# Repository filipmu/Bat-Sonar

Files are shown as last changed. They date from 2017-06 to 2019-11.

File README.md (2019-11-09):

# Bat-Sonar
Bat like sonar sensor that can track multiple targets and estimate angle of arrival using chirps and cross correlation in near real time.  Code for a ARM Cortex signal processing project I completed and published on hackaday.io. 

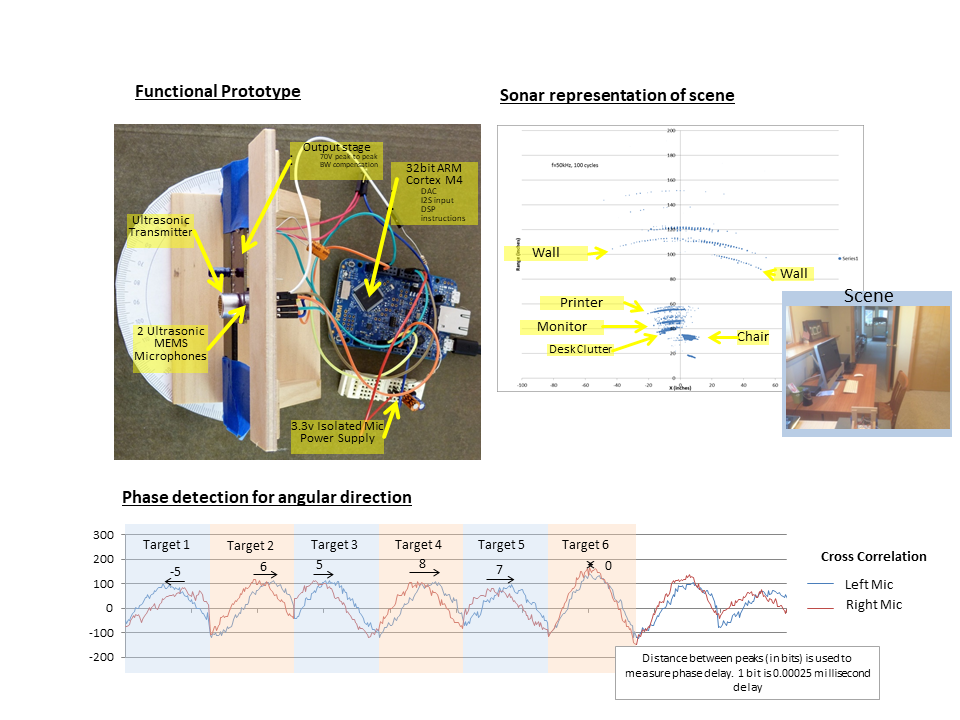
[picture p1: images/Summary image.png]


## Video
This video shows the sensor in action.  The left graph shows the identified targets.  The size of the circles indicates the strength, and the location on the graph is their measured location.  The graph on the right shows the cross correlation signal vs distance.  The first step is pressing a switch on the board to calibrate and baseline the sensor.  Then the video shows the sensor identifying various targets.:https://vimeo.com/250041155

## How it works
The approach works natively on the 1-bit PDM output of MEMS microphones.  Since the sample rate is 4MHz, very accurate phase comparison can be done. This approach takes advantage of how the cross correlation problem simplifies when its matching a simple square wave chirp with a 1-bit PDM stream. In this case its a sum of delays with terms reflecting the signal level changes in the chirp  and delays reflecting the length of each pulse in the chirp.  This reduces the computational complexity significantly.  Note that its done in the time domain, not using the FFT as is typical with higher resolution digital samples.  The Cortex M4 has SIMD (Single Instruction Multiple Data) and DSP instructions that I carefully tuned to maximize computation speed. The theory is in this paper: :http://www.kurosawa.ip.titech.ac.jp/publications/papers/ieice08sh.pdf
 
 A much more detailed description of how it works can be found at :https://hackaday.io/project/29512-bat-sonar/details

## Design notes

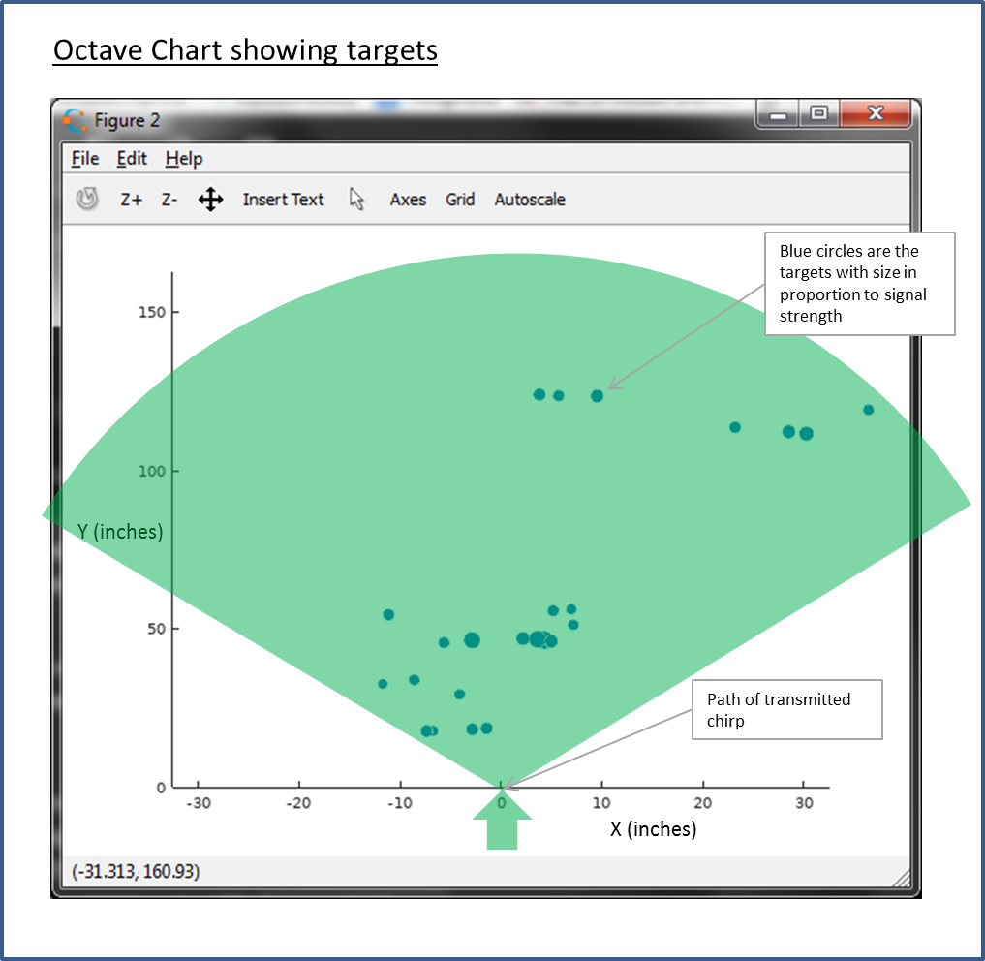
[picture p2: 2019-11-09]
images/octave chart showing targets.png

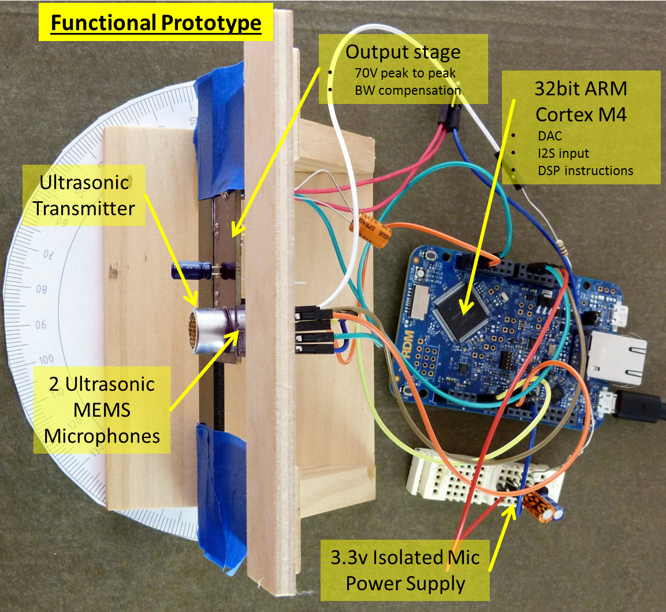
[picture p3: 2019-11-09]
images/labelled picture.png

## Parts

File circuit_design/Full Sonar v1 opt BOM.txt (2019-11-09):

Partlist exported from C:/Users/Filip/eagle/projects/Sonar/Full Sonar v1 opt.sch at 2/24/2018 7:42 AM

Qty Value                      Device                     Package                    Parts                                    Description                                                                   
1                              DIODE_SCHOTTKYMICROSMP     DIODE_SCHOTTKY_MICROSMP    D1                                       Schottky Power Rectifier                                                      
1                              MA05-1                     MA05-1                     SV1                                      PIN HEADER                                                                    
1   +5-9v                      MA02-1                     MA02-1                     J6                                                                                                                     
1   .1uF                       C-USC0603                  C0603                      C14                                      CAPACITOR, American symbol                                                    
9   0.1uF                      C-USC0603                  C0603                      C2, C5, C6, C10, C11, C16, C17, C18, C19 CAPACITOR, American symbol                                                    
2   0.1uF                      C-USC0603K                 C0603K                     C15, C20                                 CAPACITOR, American symbol                                                    
1   10                         R-US_R0603                 R0603                      R13                                      RESISTOR, American symbol                                                     
5   100K                       R-US_R0603                 R0603                      R2, R5, R6, R7, R8                       RESISTOR, American symbol                                                     
2   10K                        R-US_R0603                 R0603                      R3, R4                                   RESISTOR, American symbol                                                     
1   10uF                       C-USC0603                  C0603                      C21                                      CAPACITOR, American symbol                                                    
2   10uF                       C-USC1206                  C1206                      C1, C23                                  CAPACITOR, American symbol                                                    
1   15                         R-US_R0603                 R0603                      R16                                      RESISTOR, American symbol                                                     
2   1K                         R-US_R0603                 R0603                      R12, R18                                 RESISTOR, American symbol                                                     
2   1uF                        C-USC0603                  C0603                      C3, C7                                   CAPACITOR, American symbol                                                    
1   20K                        R-US_R0603                 R0603                      R9                                       RESISTOR, American symbol                                                     
3   22uF                       C-USC0805                  C0805                      C8, C9, C22                              CAPACITOR, American symbol                                                    
1   22uH                       INDUCTOR7                  INDUCTOR_BOURNS_SRN3012TA  L1                                                                                                                     
1   240K                       R-US_R0603                 R0603                      R10                                      RESISTOR, American symbol                                                     
1   4.7uF                      CPOLA                      TE-A-3216                  C13                                      polarized SMD caps                                                            
1   40V                        TESTPAD""                  TESTPAD                    T2                                                                                                                     
2   499                        R-US_R0603                 R0603                      R1, R11                                  RESISTOR, American symbol                                                     
1   5uH                        INDUCTOR                   INDUCTOR_BOURNS_SDR0503    L2                                                                                                                     
1   65                         R-US_R0603                 R0603                      R17                                      RESISTOR, American symbol                                                     
1   A/D                        MA03-1                     MA03-1                     J4                                       PIN HEADER                                                                    
1   CLV1L-FKB-CJMNQEGBB7673673 CLV1L-FKB-CJMNQEGBB7673673 SOJ150P350X372-4N          U1                                       None                                                                          
1   DAC Out                    TESTPAD""                  TESTPAD                    T                                                                                                                      
1   ECS-3225S33-500-FN-TR      ECS-3225S33-500-FN-TR      XTAL_ECS-3225S18-050-EN-TR Y1                                       Miniature SMD HCMOS tight stability crystal oscillator                        
1   EVP-BB2A9B000              EVP-BB2A9B000              SW_EVP-BB2A9B000           S2                                       SWITCH TACTILE SPST-NO 0.02A 15V                                              
1   I2C                        MA03-1                     MA03-1                     J2                                       PIN HEADER                                                                    
1   I2S Clk                    TESTPAD""                  TESTPAD                    T1                                                                                                                     
1   LD1117AS33                 LD1117AS33                 SOT223                     U$5                                                                                                                    
1   MC34072                    MC34072                    WQFN10                     IC2                                      Dual Precision, Low Cost, High Speed Op Amp +44v supply                       
1   MIC2297                    MIC2297                    MLF10                      IC1                                      40V PWM Boost Regulator White LED Driver                                      
1   MK64FN1M0VLL12             MK64FN1M0VLL12             QFP50P1600X1600X170-100N   U2                                       MCU 32-Bit K64F ARM Cortex M4 RISC 1MB Flash 1.8V/2.5V/3.3V 100-Pin LQFP Tray 
4   MOUNT-HOLE                 MOUNT-HOLE                 SCREWHOLE2-56              H1, H2, H3, H5                           MOUNTING HOLE with drill center marker                                        
1   Output                     MA05-1                     MA05-1                     SV2                                      PIN HEADER                                                                    
1   SI7006                     SI7006                     SI7006                     U$1                                      The Si7006 is an I2C Humidity and Temperature Sensor                          
2   SPH0641LU4H-1              SPH0641LU4H-1              SPH0641LU4H-1              LEFT_MIC, RIGHT_MIC                      Knowles MEMS microphone - ultrasonic range                                    
1   SWD                        62201021121                62201021121                J5                                       WR-PHD 1.27mm Dual Pin Header, 10 Pins=>Code : Con_BTB_PHD_1.27_2_62201021121 
1   UART                       MA03-1                     MA03-1                     J3                                       PIN HEADER                                                                    
1   UT-1240K-TT-R              UT-1240K-TT-R              UT-1240K-TT-R              U$2

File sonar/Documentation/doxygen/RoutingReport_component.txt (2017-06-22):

/*!
\page page_pinalloc Pin Allocation

		<h2 style='font-family: Arial;'>Pin Allocation Report</h2>
		<table cellpadding='2' border='1' style='border: 2px solid #000000;' bgcolor='WHITE' align='center'>
			<tr bgcolor='#E8E8E8'><th>Peripheral</th><th>Custom peripheral name</th><th>Peripheral description</th></tr>
			<tr bgcolor='#F8FF9A'><td>ADC0</td><td>ADC0</td><td><small>Analog-to-Digital Converter</small></td></tr>
			<tr bgcolor='#F8FF9A'><td>ADC1</td><td>ADC1</td><td><small>Analog-to-Digital Converter</small></td></tr>
			<tr bgcolor='#AFFF8E'><td>CAN0</td><td>CAN0</td><td><small>Flex Controller Area Network module</small></td></tr>
			<tr bgcolor='#EFF174'><td>CMP0</td><td>CMP0</td><td><small>High-Speed Comparator (CMP), Voltage Reference (VREF) Digital-to-Analog Converter (DAC), and Analog Mux (ANMUX)</small></td></tr>
			<tr bgcolor='#EFF174'><td>CMP1</td><td>CMP1</td><td><small>High-Speed Comparator (CMP), Voltage Reference (VREF) Digital-to-Analog Converter (DAC), and Analog Mux (ANMUX)</small></td></tr>
			<tr bgcolor='#EFF174'><td>CMP2</td><td>CMP2</td><td><small>High-Speed Comparator (CMP), Voltage Reference (VREF) Digital-to-Analog Converter (DAC), and Analog Mux (ANMUX)</small></td></tr>
			<tr bgcolor='#CEFFFF'><td>CMT</td><td>CMT</td><td><small>Carrier Modulator Timer (CMT)</small></td></tr>
			<tr bgcolor='#E5E44D'><td>DAC0</td><td>DAC0</td><td><small>12-Bit Digital-to-Analog Converter</small></td></tr>
			<tr bgcolor='#90EE67'><td>ENET</td><td>ENET</td><td><small>Ethernet MAC-NET Core</small></td></tr>
			<tr bgcolor='#B3EAFF'><td>EWM</td><td>EWM</td><td><small>External Watchdog Monitor (EWM)</small></td></tr>
			<tr bgcolor='#EBD4BD'><td>FB</td><td>FB</td><td><small>External bus Interface (FlexBus)</small></td></tr>
			<tr bgcolor='#86DAFF'><td>FTM0</td><td>FTM0</td><td><small>FlexTimer Module</small></td></tr>
			<tr bgcolor='#86DAFF'><td>FTM1</td><td>FTM1</td><td><small>FlexTimer Module</small></td></tr>
			<tr bgcolor='#86DAFF'><td>FTM2</td><td>FTM2</td><td><small>FlexTimer Module</small></td></tr>
			<tr bgcolor='#86DAFF'><td>FTM3</td><td>FTM3</td><td><small>FlexTimer Module</small></td></tr>
			<tr bgcolor='#5FE356'><td>I2C0</td><td>I2C0</td><td><small>Inter-integrated circuit bus</small></td></tr>
			<tr bgcolor='#5FE356'><td>I2C1</td><td>I2C1</td><td><small>Inter-integrated circuit bus</small></td></tr>
			<tr bgcolor='#5FE356'><td>I2C2</td><td>I2C2</td><td><small>Inter-integrated circuit bus</small></td></tr>
			<tr bgcolor='#20E04E'><td>I2S0</td><td>I2S0</td><td><small>Integrated Interchip Sound - I2S / Synchronous Audio Interface - SAI</small></td></tr>
			<tr bgcolor='#DDC7B5'><td>JTAG</td><td>JTAG</td><td><small>JTAG interface</small></td></tr>
			<tr bgcolor='#CCB6A0'><td>LLWU</td><td>LLWU</td><td><small>Low Leakage Wake-up Unit</small></td></tr>
			<tr bgcolor='#58C7FF'><td>LPTMR0</td><td>LPTMR0</td><td><small>Low Power Timer Module</small></td></tr>
			<tr bgcolor='#C7A886'><td>OSC</td><td>OSC</td><td><small>Oscillator</small></td></tr>
			<tr bgcolor='#14AFFF'><td>PDB0</td><td>PDB0</td><td><small>Programmable Delay Block</small></td></tr>
			<tr bgcolor='#F7DCFF'><td>PTA</td><td>PTA</td><td><small>General Purpose Input/Output</small></td></tr>
			<tr bgcolor='#F7DCFF'><td>PTB</td><td>PTB</td><td><small>General Purpose Input/Output</small></td></tr>
			<tr bgcolor='#F7DCFF'><td>PTC</td><td>PTC</td><td><small>General Purpose Input/Output</small></td></tr>
			<tr bgcolor='#F7DCFF'><td>PTD</td><td>PTD</td><td><small>General Purpose Input/Output</small></td></tr>
			<tr bgcolor='#F7DCFF'><td>PTE</td><td>PTE</td><td><small>General Purpose Input/Output</small></td></tr>
			<tr bgcolor='#FFE1C7'><td>RCM</td><td>RCM</td><td><small>Reset Control Module</small></td></tr>
			<tr bgcolor='#CEFFFF'><td>RTC</td><td>RTC</td><td><small>Real Time Clock - RTC</small></td></tr>
			<tr bgcolor='#00CA3A'><td>SDHC</td><td>SDHC</td><td><small>Secured Digital Host Controller</small></td></tr>
			<tr bgcolor='#DDC7B5'><td>SIM</td><td>SIM</td><td><small>System Integration Module</small></td></tr>
			<tr bgcolor='#AFFF8E'><td>SPI0</td><td>SPI0</td><td><small>Deserial Serial Peripheral Interface 0</small></td></tr>
			<tr bgcolor='#AFFF8E'><td>SPI1</td><td>SPI1</td><td><small>Deserial Serial Peripheral Interface 1</small></td></tr>
			<tr bgcolor='#AFFF8E'><td>SPI2</td><td>SPI2</td><td><small>Deserial Serial Peripheral Interface 2</small></td></tr>
			<tr bgcolor='#F7DCFF'><td>SUPPLY</td><td>SUPPLY</td><td><small>Chip power supply</small></td></tr>
			<tr bgcolor='#EBD4BD'><td>SystemControl</td><td>SystemControl</td><td><small>System control</small></td></tr>
			<tr bgcolor='#CCB6A0'><td>TPIU</td><td>TPIU</td><td><small>Trace Port Interface Unit</small></td></tr>
			<tr bgcolor='#90EE67'><td>UART0</td><td>UART0</td><td><small>Serial Communications Interface Module UART0</small></td></tr>
			<tr bgcolor='#90EE67'><td>UART1</td><td>UART1</td><td><small>Serial Communications Interface Module UART1</small></td></tr>
			<tr bgcolor='#90EE67'><td>UART2</td><td>UART2</td><td><small>Serial Communications Interface Module UART2</small></td></tr>
			<tr bgcolor='#90EE67'><td>UART3</td><td>UART3</td><td><small>Serial Communications Interface Module UART3</small></td></tr>
			<tr bgcolor='#90EE67'><td>UART4</td><td>UART4</td><td><small>Serial Communications Interface Module UART4</small></td></tr>
			<tr bgcolor='#5FE356'><td>USB0</td><td>USB0</td><td><small>Universal Serial Bus On The Go - USB0</small></td></tr>
			<tr bgcolor='#20E04E'><td>USBDCD</td><td>USBDCD</td><td><small>USB Charging port detect</small></td></tr>
			<tr bgcolor='#DCD627'><td>VREF</td><td>VREF</td><td><small>Voltage Reference</small></td></tr>
		</table>
		<br/>
		<br/>

		<h2 style='font-family: Arial;'>Routed Pins</h2>
		<table cellpadding='2' border='1' style='border: 2px solid #000000;' bgcolor='WHITE' width='100%' align='center'>
			<tr><td colspan='3'></td><th colspan='4' align='center' bgcolor='#D0D0D0'>Assigned Pin Function(s)</th></tr>
			<tr>
				<th bgcolor='#E8E8E8'>Package Pin #</th><th bgcolor='#E8E8E8'>Pin Name</th><th bgcolor='#E8E8E8'>User Assigned Signal Name</th><th bgcolor='#E8E8E8'>Assigned Peripheral</th><th bgcolor='#E8E8E8'>Assigned Function</th><th bgcolor='#E8E8E8'>Package Function</th><th bgcolor='#E8E8E8'>Dir</th>
			</tr>
			<tr>
				<td>1</td><td>ADC1_SE4a/PTE0/SPI1_PCS1/UART1_TX/SDHC0_D1/TRACE_CLKOUT/I2C1_SDA/RTC_CLKOUT</td><td><small><i>same</i></small></td>
				<td bgcolor='#F8FF9A'>ADC1</td><td bgcolor='#F8FF9A'>adc_sea4</td><td bgcolor='#F8FF9A'>alt0</td><td bgcolor='#F8FF9A'>Input</td>
			</tr>
			<tr>
				<td>2</td><td>ADC1_SE5a/PTE1/LLWU_P0/SPI1_SOUT/UART1_RX/SDHC0_D0/TRACE_D3/I2C1_SCL/SPI1_SIN</td><td><small><i>same</i></small></td>
				<td bgcolor='#F8FF9A'>ADC1</td><td bgcolor='#F8FF9A'>adc_sea5</td><td bgcolor='#F8FF9A'>alt0</td><td bgcolor='#F8FF9A'>Input</td>
			</tr>
			<tr>
				<td rowspan='3'>3</td><td rowspan='3'>ADC0_DP2/ADC1_SE6a/PTE2/LLWU_P1/SPI1_SCK/UART1_CTS_b/SDHC0_DCLK/TRACE_D2</td><td rowspan='3'><small><i>same</i></small></td>
				<td bgcolor='#F8FF9A'>ADC0</td><td bgcolor='#F8FF9A'>adc_dp2</td><td bgcolor='#F8FF9A'>alt0</td><td bgcolor='#F8FF9A'>Input</td>
			</tr>
			<tr bgcolor='#F8FF9A'><td>ADC0</td><td>adc_se2</td><td>alt0</td><td>Input</td></tr>
			<tr bgcolor='#F8FF9A'><td>ADC1</td><td>adc_sea6</td><td>alt0</td><td>Input</td></tr>
			<tr>
				<td rowspan='2'>4</td><td rowspan='2'>ADC0_DM2/ADC1_SE7a/PTE3/SPI1_SIN/UART1_RTS_b/SDHC0_CMD/TRACE_D1/SPI1_SOUT</td><td rowspan='2'><small><i>same</i></small></td>
				<td bgcolor='#F8FF9A'>ADC0</td><td bgcolor='#F8FF9A'>adc_dm2</td><td bgcolor='#F8FF9A'>alt0</td><td bgcolor='#F8FF9A'>Input</td>
			</tr>
			<tr bgcolor='#F8FF9A'><td>ADC1</td><td>adc_sea7</td><td>alt0</td><td>Input</td></tr>
			<tr>
				<td>5</td><td>PTE4/LLWU_P2/SPI1_PCS0/UART3_TX/SDHC0_D3/TRACE_D0</td><td><small><i>same</i></small></td>
				<td></td><td></td><td></td><td></td>
			</tr>
			<tr>
				<td>6</td><td>PTE5/SPI1_PCS2/UART3_RX/SDHC0_D2/FTM3_CH0</td><td><small><i>same</i></small></td>
				<td></td><td></td><td></td><td></td>
			</tr>
			<tr>
				<td>7</td><td>PTE6/SPI1_PCS3/UART3_CTS_b/I2S0_MCLK/FTM3_CH1/USB_SOF_OUT</td><td><small><i>same</i></small></td>
				<td></td><td></td><td></td><td></td>
			</tr>
			<tr>
				<td>8</td><td>VDD16</td><td><small><i>same</i></small></td>
				<td></td><td></td><td></td><td></td>
			</tr>
			<tr>
				<td>9</td><td>VSS17</td><td><small><i>same</i></small></td>
				<td></td><td></td><td></td><td></td>
			</tr>
			<tr>
				<td>10</td><td>USB0_DP</td><td><small><i>same</i></small></td>
				<td bgcolor='#5FE356'>USB0</td><td bgcolor='#5FE356'>usb_dp</td><td bgcolor='#5FE356'>alt0</td><td bgcolor='#5FE356'>Input/Output</td>
			</tr>
			<tr>
				<td>11</td><td>USB0_DM</td><td><small><i>same</i></small></td>
				<td bgcolor='#5FE356'>USB0</td><td bgcolor='#5FE356'>usb_dm</td><td bgcolor='#5FE356'>alt0</td><td bgcolor='#5FE356'>Input/Output</td>
			</tr>
			<tr>
				<td>12</td><td>VOUT33</td><td><small><i>same</i></small></td>
				<td bgcolor='#5FE356'>USB0</td><td bgcolor='#5FE356'>usb_vout</td><td bgcolor='#5FE356'>alt0</td><td bgcolor='#5FE356'>Output</td>
			</tr>
			<tr>
				<td>13</td><td>VREGIN</td><td><small><i>same</i></small></td>
				<td bgcolor='#5FE356'>USB0</td><td bgcolor='#5FE356'>usb_vrin</td><td bgcolor='#5FE356'>alt0</td><td bgcolor='#5FE356'>Input</td>
			</tr>
			<tr>
				<td rowspan='2'>14</td><td rowspan='2'>ADC0_DP1</td><td rowspan='2'><small><i>same</i></small></td>
				<td bgcolor='#F8FF9A'>ADC0</td><td bgcolor='#F8FF9A'>adc_dp1</td><td bgcolor='#F8FF9A'>alt0</td><td bgcolor='#F8FF9A'>Input</td>
			</tr>
			<tr bgcolor='#F8FF9A'><td>ADC0</td><td>adc_se1</td><td>alt0</td><td>Input</td></tr>
			<tr>
				<td rowspan='2'>15</td><td rowspan='2'>ADC0_DM1</td><td rowspan='2'><small><i>same</i></small></td>
				<td bgcolor='#F8FF9A'>ADC0</td><td bgcolor='#F8FF9A'>adc_dm1</td><td bgcolor='#F8FF9A'>alt0</td><td bgcolor='#F8FF9A'>Input</td>
			</tr>
			<tr bgcolor='#F8FF9A'><td>ADC0</td><td>adc_se20</td><td>alt0</td><td>Input</td></tr>
			<tr>
				<td rowspan='2'>16</td><td rowspan='2'>ADC1_DP1</td><td rowspan='2'><small><i>same</i></small></td>
				<td bgcolor='#F8FF9A'>ADC1</td><td bgcolor='#F8FF9A'>adc_dp1</td><td bgcolor='#F8FF9A'>alt0</td><td bgcolor='#F8FF9A'>Input</td>
			</tr>
			<tr bgcolor='#F8FF9A'><td>ADC1</td><td>adc_se1</td><td>alt0</td><td>Input</td></tr>
			<tr>
				<td rowspan='2'>17</td><td rowspan='2'>ADC1_DM1</td><td rowspan='2'><small><i>same</i></small></td>
				<td bgcolor='#F8FF9A'>ADC1</td><td bgcolor='#F8FF9A'>adc_dm1</td><td bgcolor='#F8FF9A'>alt0</td><td bgcolor='#F8FF9A'>Input</td>
			</tr>
			<tr bgcolor='#F8FF9A'><td>ADC1</td><td>adc_se20</td><td>alt0</td><td>Input</td></tr>
			<tr>
				<td rowspan='4'>18</td><td rowspan='4'>ADC0_DP0/ADC1_DP3</td><td rowspan='4'><small><i>same</i></small></td>
				<td bgcolor='#F8FF9A'>ADC0</td><td bgcolor='#F8FF9A'>adc_dp0</td><td bgcolor='#F8FF9A'>alt0</td><td bgcolor='#F8FF9A'>Input</td>
			</tr>
			<tr bgcolor='#F8FF9A'><td>ADC0</td><td>adc_se0</td><td>alt0</td><td>Input</td></tr>
			<tr bgcolor='#F8FF9A'><td>ADC1</td><td>adc_dp3</td><td>alt0</td><td>Input</td></tr>
			<tr bgcolor='#F8FF9A'><td>ADC1</td><td>adc_se3</td><td>alt0</td><td>Input</td></tr>
			<tr>
				<td rowspan='3'>19</td><td rowspan='3'>ADC0_DM0/ADC1_DM3</td><td rowspan='3'><small><i>same</i></small></td>
				<td bgcolor='#F8FF9A'>ADC0</td><td bgcolor='#F8FF9A'>adc_dm0</td><td bgcolor='#F8FF9A'>alt0</td><td bgcolor='#F8FF9A'>Input</td>
			</tr>
			<tr bgcolor='#F8FF9A'><td>ADC0</td><td>adc_se19</td><td>alt0</td><td>Input</td></tr>
			<tr bgcolor='#F8FF9A'><td>ADC1</td><td>adc_dm3</td><td>alt0</td><td>Input</td></tr>
			<tr>
				<td rowspan='4'>20</td><td rowspan='4'>ADC1_DP0/ADC0_DP3</td><td rowspan='4'><small><i>same</i></small></td>
				<td bgcolor='#F8FF9A'>ADC1</td><td bgcolor='#F8FF9A'>adc_dp0</td><td bgcolor='#F8FF9A'>alt0</td><td bgcolor='#F8FF9A'>Input</td>
			</tr>
			<tr bgcolor='#F8FF9A'><td>ADC1</td><td>adc_se0</td><td>alt0</td><td>Input</td></tr>
			<tr bgcolor='#F8FF9A'><td>ADC0</td><td>adc_dp3</td><td>alt0</td><td>Input</td></tr>
			<tr bgcolor='#F8FF9A'><td>ADC0</td><td>adc_se3</td><td>alt0</td><td>Input</td></tr>
			<tr>
				<td rowspan='3'>21</td><td rowspan='3'>ADC1_DM0/ADC0_DM3</td><td rowspan='3'><small><i>same</i></small></td>
				<td bgcolor='#F8FF9A'>ADC1</td><td bgcolor='#F8FF9A'>adc_dm0</td><td bgcolor='#F8FF9A'>alt0</td><td bgcolor='#F8FF9A'>Input</td>
			</tr>
			<tr bgcolor='#F8FF9A'><td>ADC1</td><td>adc_se19</td><td>alt0</td><td>Input</td></tr>
			<tr bgcolor='#F8FF9A'><td>ADC0</td><td>adc_dm3</td><td>alt0</td><td>Input</td></tr>
			<tr>
				<td>22</td><td>VDDA</td><td><small><i>same</i></small></td>
				<td></td><td></td><td></td><td></td>
			</tr>
			<tr>
				<td rowspan='6'>23</td><td rowspan='6'>VREFH</td><td rowspan='6'><small><i>same</i></small></td>
				<td bgcolor='#F8FF9A'>ADC0</td><td bgcolor='#F8FF9A'>adc_vrefh</td><td bgcolor='#F8FF9A'>alt0</td><td bgcolor='#F8FF9A'>Input</td>
			</tr>
			<tr bgcolor='#F8FF9A'><td>ADC0</td><td>adc_se29</td><td>alt0</td><td>Input</td></tr>
			<tr bgcolor='#F8FF9A'><td>ADC0</td><td>adc_dp29</td><td>alt0</td><td>Input</td></tr>
			<tr bgcolor='#F8FF9A'><td>ADC1</td><td>adc_vrefh</td><td>alt0</td><td>Input</td></tr>
			<tr bgcolor='#F8FF9A'><td>ADC1</td><td>adc_se29</td><td>alt0</td><td>Input</td></tr>
			<tr bgcolor='#F8FF9A'><td>ADC1</td><td>adc_dp29</td><td>alt0</td><td>Input</td></tr>
			<tr>
				<td rowspan='6'>24</td><td rowspan='6'>VREFL</td><td rowspan='6'><small><i>same</i></small></td>
				<td bgcolor='#F8FF9A'>ADC0</td><td bgcolor='#F8FF9A'>adc_vrefl</td><td bgcolor='#F8FF9A'>alt0</td><td bgcolor='#F8FF9A'>Input</td>
			</tr>
			<tr bgcolor='#F8FF9A'><td>ADC0</td><td>adc_se30</td><td>alt0</td><td>Input</td></tr>
			<tr bgcolor='#F8FF9A'><td>ADC0</td><td>adc_dm29</td><td>alt0</td><td>Input</td></tr>
			<tr bgcolor='#F8FF9A'><td>ADC1</td><td>adc_vrefl</td><td>alt0</td><td>Input</td></tr>
			<tr bgcolor='#F8FF9A'><td>ADC1</td><td>adc_se30</td><td>alt0</td><td>Input</td></tr>
			<tr bgcolor='#F8FF9A'><td>ADC1</td><td>adc_dm29</td><td>alt0</td><td>Input</td></tr>
			<tr>
				<td>25</td><td>VSSA</td><td><small><i>same</i></small></td>
				<td></td><td></td><td></td><td></td>
			</tr>
			<tr>
				<td rowspan='6'>26</td><td rowspan='6'>VREF_OUT/CMP1_IN5/CMP0_IN5/ADC1_SE18</td><td rowspan='6'><small><i>same</i></small></td>
				<td bgcolor='#DCD627'>VREF</td><td bgcolor='#DCD627'>vref_out</td><td bgcolor='#DCD627'>alt0</td><td bgcolor='#DCD627'>Output</td>
			</tr>
			<tr bgcolor='#EFF174'><td>CMP1</td><td>cmp_pos5</td><td>alt0</td><td>Input</td></tr>
			<tr bgcolor='#EFF174'><td>CMP1</td><td>cmp_neg5</td><td>alt0</td><td>Input</td></tr>
			<tr bgcolor='#EFF174'><td>CMP0</td><td>cmp_pos5</td><td>alt0</td><td>Input</td></tr>
			<tr bgcolor='#EFF174'><td>CMP0</td><td>cmp_neg5</td><td>alt0</td><td>Input</td></tr>
			<tr bgcolor='#F8FF9A'><td>ADC1</td><td>adc_se18</td><td>alt0</td><td>Input</td></tr>
			<tr>
				<td rowspan='4'>27</td><td rowspan='4'>DAC0_OUT/CMP1_IN3/ADC0_SE23</td><td rowspan='4'><small><i>same</i></small></td>
				<td bgcolor='#E5E44D'>DAC0</td><td bgcolor='#E5E44D'>dac_out</td><td bgcolor='#E5E44D'>alt0</td><td bgcolor='#E5E44D'>Output</td>
			</tr>
			<tr bgcolor='#EFF174'><td>CMP1</td><td>cmp_pos3</td><td>alt0</td><td>Input</td></tr>
			<tr bgcolor='#EFF174'><td>CMP1</td><td>cmp_neg3</td><td>alt0</td><td>Input</td></tr>
			<tr bgcolor='#F8FF9A'><td>ADC0</td><td>adc_se23</td><td>alt0</td><td>Input</td></tr>
			<tr>
				<td>28</td><td>XTAL32</td><td><small><i>same</i></small></td>
				<td bgcolor='#CEFFFF'>RTC</td><td bgcolor='#CEFFFF'>rtc_xtal</td><td bgcolor='#CEFFFF'>alt0</td><td bgcolor='#CEFFFF'>Output</td>
			</tr>
			<tr>
				<td>29</td><td>EXTAL32</td><td><small><i>same</i></small></td>
				<td bgcolor='#CEFFFF'>RTC</td><td bgcolor='#CEFFFF'>rtc_extal</td><td bgcolor='#CEFFFF'>alt0</td><td bgcolor='#CEFFFF'>Input</td>
			</tr>
			<tr>
				<td>30</td><td>VBAT</td><td><small><i>same</i></small></td>
				<td bgcolor='#CEFFFF'>RTC</td><td bgcolor='#CEFFFF'>rtc_vbat</td><td bgcolor='#CEFFFF'>alt0</td><td bgcolor='#CEFFFF'>Input</td>
			</tr>
			<tr>
				<td>31</td><td>ADC0_SE17/PTE24/UART4_TX/I2C0_SCL/EWM_OUT_b</td><td><small><i>same</i></small></td>
				<td bgcolor='#F8FF9A'>ADC0</td><td bgcolor='#F8FF9A'>adc_se17</td><td bgcolor='#F8FF9A'>alt0</td><td bgcolor='#F8FF9A'>Input</td>
			</tr>
			<tr>
				<td>32</td><td>ADC0_SE18/PTE25/UART4_RX/I2C0_SDA/EWM_IN</td><td><small><i>same</i></small></td>
				<td bgcolor='#F8FF9A'>ADC0</td><td bgcolor='#F8FF9A'>adc_se18</td><td bgcolor='#F8FF9A'>alt0</td><td bgcolor='#F8FF9A'>Input</td>
			</tr>
			<tr>
				<td>33</td><td>PTE26/ENET_1588_CLKIN/UART4_CTS_b/RTC_CLKOUT/USB_CLKIN</td><td><small><i>same</i></small></td>
				<td></td><td></td><td></td><td></td>
			</tr>
			<tr>
				<td>34</td><td>PTA0/UART0_CTS_b/UART0_COL_b/FTM0_CH5/JTAG_TCLK/SWD_CLK/EZP_CLK</td><td><small><i>same</i></small></td>
				<td bgcolor='#DDC7B5'>JTAG</td><td bgcolor='#DDC7B5'>jtag_clk</td><td bgcolor='#DDC7B5'>alt7</td><td bgcolor='#DDC7B5'>Input</td>
			</tr>
			<tr>
				<td>35</td><td>PTA1/UART0_RX/FTM0_CH6/JTAG_TDI/EZP_DI</td><td><small><i>same</i></small></td>
				<td bgcolor='#DDC7B5'>JTAG</td><td bgcolor='#DDC7B5'>jtag_di</td><td bgcolor='#DDC7B5'>alt7</td><td bgcolor='#DDC7B5'>Input</td>
			</tr>
			<tr>
				<td rowspan='3'>36</td><td rowspan='3'>PTA2/UART0_TX/FTM0_CH7/JTAG_TDO/TRACE_SWO/EZP_DO</td><td rowspan='3'><small><i>same</i></small></td>
				<td bgcolor='#DDC7B5'>JTAG</td><td bgcolor='#DDC7B5'>jtag_do</td><td bgcolor='#DDC7B5'>alt7</td><td bgcolor='#DDC7B5'>Output</td>
			</tr>
			<tr bgcolor='#CCB6A0'><td>TPIU</td><td>tpiu_swo</td><td>alt7</td><td>Output</td></tr>
			<tr bgcolor='#969696'><td>non-peripheral</td><td>TRACE_SWO</td><td>alt7</td><td>Not Specified</td></tr>
			<tr>
				<td>37</td><td>PTA3/UART0_RTS_b/FTM0_CH0/JTAG_TMS/SWD_DIO</td><td><small><i>same</i></small></td>
				<td bgcolor='#DDC7B5'>JTAG</td><td bgcolor='#DDC7B5'>jtag_ms</td><td bgcolor='#DDC7B5'>alt7</td><td bgcolor='#DDC7B5'>Input/Output</td>
			</tr>
			<tr>
				<td rowspan='2'>38</td><td rowspan='2'>PTA4/LLWU_P3/FTM0_CH1/NMI_b/EZP_CS_b</td><td rowspan='2'><small><i>same</i></small></td>
				<td bgcolor='#EBD4BD'>SystemControl</td><td bgcolor='#EBD4BD'>scb_nmi</td><td bgcolor='#EBD4BD'>alt7</td><td bgcolor='#EBD4BD'>Input</td>
			</tr>
			<tr bgcolor='#969696'><td>non-peripheral</td><td>NMI</td><td>alt7</td><td>Not Specified</td></tr>
			<tr>
				<td>39</td><td>PTA5/USB_CLKIN/FTM0_CH2/RMII0_RXER/MII0_RXER/CMP2_OUT/I2S0_TX_BCLK/JTAG_TRST_b</td><td><small><i>same</i></small></td>
				<td></td><td></td><td></td><td></td>
			</tr>
			<tr>
				<td>40</td><td>VDD63</td><td><small><i>same</i></small></td>
				<td></td><td></td><td></td><td></td>
			</tr>
			<tr>
				<td>41</td><td>VSS64</td><td><small><i>same</i></small></td>
				<td></td><td></td><td></td><td></td>
			</tr>
			<tr>
				<td rowspan='3'>42</td><td rowspan='3'>CMP2_IN0/PTA12/CAN0_TX/FTM1_CH0/RMII0_RXD1/MII0_RXD1/I2C2_SCL/I2S0_TXD0/FTM1_QD_PHA</td><td rowspan='3'><small><i>same</i></small></td>
				<td bgcolor='#EFF174'>CMP2</td><td bgcolor='#EFF174'>cmp_pos0</td><td bgcolor='#EFF174'>alt0</td><td bgcolor='#EFF174'>Input</td>
			</tr>
			<tr bgcolor='#EFF174'><td>CMP2</td><td>cmp_neg0</td><td>alt0</td><td>Input</td></tr>
			<tr bgcolor='#EFF174'><td>CMP2</td><td>cmp_in0</td><td>alt0</td><td>Input</td></tr>
			<tr>
				<td rowspan='3'>43</td><td rowspan='3'>CMP2_IN1/PTA13/LLWU_P4/CAN0_RX/FTM1_CH1/RMII0_RXD0/MII0_RXD0/I2C2_SDA/I2S0_TX_FS/FTM1_QD_PHB</td><td rowspan='3'><small><i>same</i></small></td>
				<td bgcolor='#EFF174'>CMP2</td><td bgcolor='#EFF174'>cmp_pos1</td><td bgcolor='#EFF174'>alt0</td><td bgcolor='#EFF174'>Input</td>
			</tr>
			<tr bgcolor='#EFF174'><td>CMP2</td><td>cmp_neg1</td><td>alt0</td><td>Input</td></tr>
			<tr bgcolor='#EFF174'><td>CMP2</td><td>cmp_in1</td><td>alt0</td><td>Input</td></tr>
			<tr>
				<td>44</td><td>PTA14/SPI0_PCS0/UART0_TX/RMII0_CRS_DV/MII0_RXDV/I2C2_SCL/I2S0_RX_BCLK/I2S0_TXD1</td><td><small><i>same</i></small></td>
				<td></td><td></td><td></td><td></td>
			</tr>
			<tr>
				<td>45</td><td>PTA15/SPI0_SCK/UART0_RX/RMII0_TXEN/MII0_TXEN/I2S0_RXD0</td><td><small><i>same</i></small></td>
				<td></td><td></td><td></td><td></td>
			</tr>
			<tr>
				<td>46</td><td>PTA16/SPI0_SOUT/UART0_CTS_b/UART0_COL_b/RMII0_TXD0/MII0_TXD0/I2S0_RX_FS/I2S0_RXD1</td><td><small><i>same</i></small></td>
				<td></td><td></td><td></td><td></td>
			</tr>
			<tr>
				<td>47</td><td>ADC1_SE17/PTA17/SPI0_SIN/UART0_RTS_b/RMII0_TXD1/MII0_TXD1/I2S0_MCLK</td><td><small><i>same</i></small></td>
				<td bgcolor='#F8FF9A'>ADC1</td><td bgcolor='#F8FF9A'>adc_se17</td><td bgcolor='#F8FF9A'>alt0</td><td bgcolor='#F8FF9A'>Input</td>
			</tr>
			<tr>
				<td>48</td><td>VDD78</td><td><small><i>same</i></small></td>
				<td></td><td></td><td></td><td></td>
			</tr>
			<tr>
				<td>49</td><td>VSS79</td><td><small><i>same</i></small></td>
				<td></td><td></td><td></td><td></td>
			</tr>
			<tr>
				<td rowspan='2'>50</td><td rowspan='2'>EXTAL0/PTA18/FTM0_FLT2/FTM_CLKIN0</td><td rowspan='2'><small><i>same</i></small></td>
				<td bgcolor='#90EE67'>ENET</td><td bgcolor='#90EE67'>rmii_clkin</td><td bgcolor='#90EE67'>alt0</td><td bgcolor='#90EE67'>Input</td>
			</tr>
			<tr bgcolor='#C7A886'><td>OSC</td><td>extal</td><td>alt0</td><td>Input</td></tr>
			<tr>
				<td>51</td><td>XTAL0/PTA19/FTM1_FLT0/FTM_CLKIN1/LPTMR0_ALT1</td><td><small><i>same</i></small></td>
				<td bgcolor='#C7A886'>OSC</td><td bgcolor='#C7A886'>xtal</td><td bgcolor='#C7A886'>alt0</td><td bgcolor='#C7A886'>Output</td>
			</tr>
			<tr>
				<td>52</td><td>RESET_b</td><td><small><i>same</i></small></td>
				<td bgcolor='#FFE1C7'>RCM</td><td bgcolor='#FFE1C7'>reset</td><td bgcolor='#FFE1C7'>alt0</td><td bgcolor='#FFE1C7'>Input</td>
			</tr>
			<tr>
				<td rowspan='2'>53</td><td rowspan='2'>ADC0_SE8/ADC1_SE8/PTB0/LLWU_P5/I2C0_SCL/FTM1_CH0/RMII0_MDIO/MII0_MDIO/FTM1_QD_PHA</td><td rowspan='2'><small><i>same</i></small></td>
				<td bgcolor='#F8FF9A'>ADC0</td><td bgcolor='#F8FF9A'>adc_se8</td><td bgcolor='#F8FF9A'>alt0</td><td bgcolor='#F8FF9A'>Input</td>
			</tr>
			<tr bgcolor='#F8FF9A'><td>ADC1</td><td>adc_se8</td><td>alt0</td><td>Input</td></tr>
			<tr>
				<td rowspan='2'>54</td><td rowspan='2'>ADC0_SE9/ADC1_SE9/PTB1/I2C0_SDA/FTM1_CH1/RMII0_MDC/MII0_MDC/FTM1_QD_PHB</td><td rowspan='2'><small><i>same</i></small></td>
				<td bgcolor='#F8FF9A'>ADC0</td><td bgcolor='#F8FF9A'>adc_se9</td><td bgcolor='#F8FF9A'>alt0</td><td bgcolor='#F8FF9A'>Input</td>
			</tr>
			<tr bgcolor='#F8FF9A'><td>ADC1</td><td>adc_se9</td><td>alt0</td><td>Input</td></tr>
			<tr>
				<td>55</td><td>ADC0_SE12/PTB2/I2C0_SCL/UART0_RTS_b/ENET0_1588_TMR0/FTM0_FLT3</td><td><small><i>same</i></small></td>
				<td bgcolor='#F8FF9A'>ADC0</td><td bgcolor='#F8FF9A'>adc_se12</td><td bgcolor='#F8FF9A'>alt0</td><td bgcolor='#F8FF9A'>Input</td>
			</tr>
			<tr>
				<td>56</td><td>ADC0_SE13/PTB3/I2C0_SDA/UART0_CTS_b/UART0_COL_b/ENET0_1588_TMR1/FTM0_FLT0</td><td><small><i>same</i></small></td>
				<td bgcolor='#F8FF9A'>ADC0</td><td bgcolor='#F8FF9A'>adc_se13</td><td bgcolor='#F8FF9A'>alt0</td><td bgcolor='#F8FF9A'>Input</td>
			</tr>
			<tr>
				<td>57</td><td>PTB9/SPI1_PCS1/UART3_CTS_b/FB_AD20</td><td><small><i>same</i></small></td>
				<td></td><td></td><td></td><td></td>
			</tr>
			<tr>
				<td>58</td><td>ADC1_SE14/PTB10/SPI1_PCS0/UART3_RX/FB_AD19/FTM0_FLT1</td><td><small><i>same</i></small></td>
				<td bgcolor='#F8FF9A'>ADC1</td><td bgcolor='#F8FF9A'>adc_se14</td><td bgcolor='#F8FF9A'>alt0</td><td bgcolor='#F8FF9A'>Input</td>
			</tr>
			<tr>
				<td>59</td><td>ADC1_SE15/PTB11/SPI1_SCK/UART3_TX/FB_AD18/FTM0_FLT2</td><td><small><i>same</i></small></td>
				<td bgcolor='#F8FF9A'>ADC1</td><td bgcolor='#F8FF9A'>adc_se15</td><td bgcolor='#F8FF9A'>alt0</td><td bgcolor='#F8FF9A'>Input</td>
			</tr>
			<tr>
				<td>60</td><td>VSS103</td><td><small><i>same</i></small></td>
				<td></td><td></td><td></td><td></td>
			</tr>
			<tr>
				<td>61</td><td>VDD104</td><td><small><i>same</i></small></td>
				<td></td><td></td><td></td><td></td>
			</tr>
			<tr>
				<td>62</td><td>PTB16/SPI1_SOUT/UART0_RX/FTM_CLKIN0/FB_AD17/EWM_IN</td><td><small><i>same</i></small></td>
				<td bgcolor='#90EE67'>UART0</td><td bgcolor='#90EE67'>uart_rx</td><td bgcolor='#90EE67'>alt3</td><td bgcolor='#90EE67'>Input</td>
			</tr>
			<tr>
				<td>63</td><td>PTB17/SPI1_SIN/UART0_TX/FTM_CLKIN1/FB_AD16/EWM_OUT_b</td><td><small><i>same</i></small></td>
				<td bgcolor='#90EE67'>UART0</td><td bgcolor='#90EE67'>uart_tx</td><td bgcolor='#90EE67'>alt3</td><td bgcolor='#90EE67'>Output</td>
			</tr>
			<tr>
				<td>64</td><td>PTB18/CAN0_TX/FTM2_CH0/I2S0_TX_BCLK/FB_AD15/FTM2_QD_PHA</td><td><small><i>same</i></small></td>
				<td bgcolor='#20E04E'>I2S0</td><td bgcolor='#20E04E'>i2s_tclk</td><td bgcolor='#20E04E'>alt4</td><td bgcolor='#20E04E'>Output</td>
			</tr>
			<tr>
				<td>65</td><td>PTB19/CAN0_RX/FTM2_CH1/I2S0_TX_FS/FB_OE_b/FTM2_QD_PHB</td><td><small><i>same</i></small></td>
				<td></td><td></td><td></td><td></td>
			</tr>
			<tr>
				<td>66</td><td>PTB20/SPI2_PCS0/FB_AD31/CMP0_OUT</td><td><small><i>same</i></small></td>
				<td></td><td></td><td></td><td></td>
			</tr>
			<tr>
				<td>67</td><td>PTB21/SPI2_SCK/FB_AD30/CMP1_OUT</td><td><small><i>same</i></small></td>
				<td></td><td></td><td></td><td></td>
			</tr>
			<tr>
				<td>68</td><td>PTB22/SPI2_SOUT/FB_AD29/CMP2_OUT</td><td><small><i>same</i></small></td>
				<td></td><td></td><td></td><td></td>
			</tr>
			<tr>
				<td>69</td><td>PTB23/SPI2_SIN/SPI0_PCS5/FB_AD28</td><td><small><i>same</i></small></td>
				<td bgcolor='#AFFF8E'>SPI2</td><td bgcolor='#AFFF8E'>spi_rxd</td><td bgcolor='#AFFF8E'>alt2</td><td bgcolor='#AFFF8E'>Input</td>
			</tr>
			<tr>
				<td>70</td><td>ADC0_SE14/PTC0/SPI0_PCS4/PDB0_EXTRG/USB_SOF_OUT/FB_AD14/I2S0_TXD1</td><td><small><i>same</i></small></td>
				<td bgcolor='#F8FF9A'>ADC0</td><td bgcolor='#F8FF9A'>adc_se14</td><td bgcolor='#F8FF9A'>alt0</td><td bgcolor='#F8FF9A'>Input</td>
			</tr>
			<tr>
				<td>71</td><td>ADC0_SE15/PTC1/LLWU_P6/SPI0_PCS3/UART1_RTS_b/FTM0_CH0/FB_AD13/I2S0_TXD0</td><td><small><i>same</i></small></td>
				<td bgcolor='#F8FF9A'>ADC0</td><td bgcolor='#F8FF9A'>adc_se15</td><td bgcolor='#F8FF9A'>alt0</td><td bgcolor='#F8FF9A'>Input</td>
			</tr>
			<tr>
				<td>72</td><td>ADC0_SE4b/CMP1_IN0/PTC2/SPI0_PCS2/UART1_CTS_b/FTM0_CH1/FB_AD12/I2S0_TX_FS</td><td><small><i>same</i></small></td>
				<td bgcolor='#F7DCFF'>PTC</td><td bgcolor='#F7DCFF'>port2</td><td bgcolor='#F7DCFF'>alt1</td><td bgcolor='#F7DCFF'>Output</td>
			</tr>
			<tr>
				<td rowspan='2'>73</td><td rowspan='2'>CMP1_IN1/PTC3/LLWU_P7/SPI0_PCS1/UART1_RX/FTM0_CH2/CLKOUT/I2S0_TX_BCLK</td><td rowspan='2'><small><i>same</i></small></td>
				<td bgcolor='#F7DCFF'>PTC</td><td bgcolor='#F7DCFF'>port3</td><td bgcolor='#F7DCFF'>alt1</td><td bgcolor='#F7DCFF'>Output</td>
			</tr>
			<tr bgcolor='#CCB6A0'><td>LLWU</td><td>llwu_wakeup7</td><td>alt1</td><td>Input</td></tr>
			<tr>
				<td>74</td><td>VSS117</td><td><small><i>same</i></small></td>
				<td></td><td></td><td></td><td></td>
			</tr>
			<tr>
				<td>75</td><td>VDD118</td><td><small><i>same</i></small></td>
				<td></td><td></td><td></td><td></td>
			</tr>
			<tr>
				<td>76</td><td>PTC4/LLWU_P8/SPI0_PCS0/UART1_TX/FTM0_CH3/FB_AD11/CMP1_OUT</td><td><small><i>same</i></small></td>
				<td></td><td></td><td></td><td></td>
			</tr>
			<tr>
				<td>77</td><td>PTC5/LLWU_P9/SPI0_SCK/LPTMR0_ALT2/I2S0_RXD0/FB_AD10/CMP0_OUT/FTM0_CH2</td><td><small><i>same</i></small></td>
				<td bgcolor='#20E04E'>I2S0</td><td bgcolor='#20E04E'>i2s_rxd0</td><td bgcolor='#20E04E'>alt4</td><td bgcolor='#20E04E'>Input</td>
			</tr>
			<tr>
				<td rowspan='2'>78</td><td rowspan='2'>CMP0_IN0/PTC6/LLWU_P10/SPI0_SOUT/PDB0_EXTRG/I2S0_RX_BCLK/FB_AD9/I2S0_MCLK</td><td rowspan='2'><small><i>same</i></small></td>
				<td bgcolor='#F7DCFF'>PTC</td><td bgcolor='#F7DCFF'>port6</td><td bgcolor='#F7DCFF'>alt1</td><td bgcolor='#F7DCFF'>Input</td>
			</tr>
			<tr bgcolor='#CCB6A0'><td>LLWU</td><td>llwu_wakeup10</td><td>alt1</td><td>Input</td></tr>
			<tr>
				<td>79</td><td>CMP0_IN1/PTC7/SPI0_SIN/USB_SOF_OUT/I2S0_RX_FS/FB_AD8</td><td><small><i>same</i></small></td>
				<td bgcolor='#F7DCFF'>PTC</td><td bgcolor='#F7DCFF'>port7</td><td bgcolor='#F7DCFF'>alt1</td><td bgcolor='#F7DCFF'>Output</td>
			</tr>
			<tr>
				<td rowspan='4'>80</td><td rowspan='4'>ADC1_SE4b/CMP0_IN2/PTC8/FTM3_CH4/I2S0_MCLK/FB_AD7</td><td rowspan='4'><small><i>same</i></small></td>
				<td bgcolor='#F8FF9A'>ADC1</td><td bgcolor='#F8FF9A'>adc_seb4</td><td bgcolor='#F8FF9A'>alt0</td><td bgcolor='#F8FF9A'>Input</td>
			</tr>
			<tr bgcolor='#EFF174'><td>CMP0</td><td>cmp_pos2</td><td>alt0</td><td>Input</td></tr>
			<tr bgcolor='#EFF174'><td>CMP0</td><td>cmp_neg2</td><td>alt0</td><td>Input</td></tr>
			<tr bgcolor='#EFF174'><td>CMP0</td><td>cmp_in2</td><td>alt0</td><td>Input</td></tr>
			<tr>
				<td>81</td><td>ADC1_SE5b/CMP0_IN3/PTC9/FTM3_CH5/I2S0_RX_BCLK/FB_AD6/FTM2_FLT0</td><td><small><i>same</i></small></td>
				<td bgcolor='#20E04E'>I2S0</td><td bgcolor='#20E04E'>i2s_rclk</td><td bgcolor='#20E04E'>alt4</td><td bgcolor='#20E04E'>Output</td>
			</tr>
			<tr>
				<td>82</td><td>ADC1_SE6b/PTC10/I2C1_SCL/FTM3_CH6/I2S0_RX_FS/FB_AD5</td><td><small><i>same</i></small></td>
				<td bgcolor='#F8FF9A'>ADC1</td><td bgcolor='#F8FF9A'>adc_seb6</td><td bgcolor='#F8FF9A'>alt0</td><td bgcolor='#F8FF9A'>Input</td>
			</tr>
			<tr>
				<td>83</td><td>ADC1_SE7b/PTC11/LLWU_P11/I2C1_SDA/FTM3_CH7/I2S0_RXD1/FB_RW_b</td><td><small><i>same</i></small></td>
				<td bgcolor='#20E04E'>I2S0</td><td bgcolor='#20E04E'>i2s_rxd1</td><td bgcolor='#20E04E'>alt4</td><td bgcolor='#20E04E'>Input</td>
			</tr>
			<tr>
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

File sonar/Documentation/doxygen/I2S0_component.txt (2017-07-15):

/*!
  \page I2S0 I2S0 (Init_I2S)
**          This file implements the I2S (I2S0) module initialization
**          according to the Peripheral Initialization settings, and
**          defines interrupt service routines prototypes.
**

- \subpage I2S0_settings
- \subpage I2S0_regs_overview  
- \subpage I2S0_regs_details
- \ref I2S0_module "Component documentation" 
\page I2S0_regs_overview Registers Initialization Overview
This page contains the initialization values for the registers of the peripheral(s) configured
by the component. 
<table>
<tr><td colspan="4" class="ttitle1">I2S0 Initialization</td></tr>
<tr><td class="ttitle2">Address</td><td class="ttitle2">Register</td><td class="ttitle2">Register Value</td><td class="ttitle2">Register Description</td></tr>
<tr><td>0x4002F100</td><td>I2S0_MCR</td>
<td class="regNotResetVal">0x41000000</td>
 <td>I2S0_MCR register, peripheral I2S0.</td></tr>
<tr><td>0x4002F104</td><td>I2S0_MDR</td>
<td class="regNotResetVal">0x00003004</td>
 <td>I2S0_MDR register, peripheral I2S0.</td></tr>
<tr><td>0x4002F000</td><td>I2S0_TCSR</td>
<td class="regNotResetVal">0x321FE000</td>
 <td>I2S0_TCSR register, peripheral I2S0.</td></tr>
<tr><td>0x4002F080</td><td>I2S0_RCSR</td>
<td class="regNotResetVal">0xF21C0100</td>
 <td>I2S0_RCSR register, peripheral I2S0.</td></tr>
<tr><td>0x4002F004</td><td>I2S0_TCR1</td>
<td class="regResetVal">0x00000000</td>
 <td>I2S0_TCR1 register, peripheral I2S0.</td></tr>
<tr><td>0x4002F084</td><td>I2S0_RCR1</td>
<td class="regNotResetVal">0x00000005</td>
 <td>I2S0_RCR1 register, peripheral I2S0.</td></tr>
<tr><td>0x4002F008</td><td>I2S0_TCR2</td>
<td class="regNotResetVal">0x05000009</td>
 <td>I2S0_TCR2 register, peripheral I2S0.</td></tr>
<tr><td>0x4002F088</td><td>I2S0_RCR2</td>
<td class="regNotResetVal">0x07000004</td>
 <td>I2S0_RCR2 register, peripheral I2S0.</td></tr>
<tr><td>0x4002F00C</td><td>I2S0_TCR3</td>
<td class="regResetVal">0x00000000</td>
 <td>I2S0_TCR3 register, peripheral I2S0.</td></tr>
<tr><td>0x4002F08C</td><td>I2S0_RCR3</td>
<td class="regNotResetVal">0x0003001F</td>
 <td>I2S0_RCR3 register, peripheral I2S0.</td></tr>
<tr><td>0x4002F010</td><td>I2S0_TCR4</td>
<td class="regResetVal">0x00000000</td>
 <td>I2S0_TCR4 register, peripheral I2S0.</td></tr>
<tr><td>0x4002F090</td><td>I2S0_RCR4</td>
<td class="regNotResetVal">0x00000001</td>
 <td>I2S0_RCR4 register, peripheral I2S0.</td></tr>
<tr><td>0x4002F014</td><td>I2S0_TCR5</td>
<td class="regNotResetVal">0x07070000</td>
 <td>I2S0_TCR5 register, peripheral I2S0.</td></tr>
<tr><td>0x4002F094</td><td>I2S0_RCR5</td>
<td class="regNotResetVal">0x1F1F0000</td>
 <td>I2S0_RCR5 register, peripheral I2S0.</td></tr>
<tr><td>0x4002F060</td><td>I2S0_TMR</td>
<td class="regResetVal">0x00000000</td>
 <td>I2S0_TMR register, peripheral I2S0.</td></tr>
<tr><td>0x4002F0E0</td><td>I2S0_RMR</td>
<td class="regResetVal">0x00000000</td>
 <td>I2S0_RMR register, peripheral I2S0.</td></tr>
</table>
Color Denotes Reset Value
<br/>
\page I2S0_regs_details Register Initialization Details
This page contains detailed description of initialization values for the 
registers of the peripheral(s) configured by the component. 

<div class="reghdr1">I2S0_MCR</div>
<div class="regdiag">
<table class="regtbl">
<tr class="trd1r">
<td class="trd1c">Bit</td><td>31</td><td>30</td><td>29</td><td>28</td><td>27</td><td>26</td><td>25</td><td>24</td><td>23</td>
<td>22</td><td>21</td><td>20</td><td>19</td><td>18</td><td>17</td><td>16</td>
</tr>
<tr>
<td class="trd1c">R</td><td colspan="1" rowspan="1">DUF</td><td colspan="1" rowspan="2">MOE</td>
<td colspan="1" rowspan="2">-</td><td colspan="1" rowspan="2">-</td><td colspan="1" rowspan="2">-</td>
<td colspan="1" rowspan="2">-</td><td colspan="2" rowspan="2">MICS</td><td colspan="1" rowspan="2">-</td>
<td colspan="1" rowspan="2">-</td><td colspan="1" rowspan="2">-</td><td colspan="1" rowspan="2">-</td>
<td colspan="1" rowspan="2">-</td><td colspan="1" rowspan="2">-</td><td colspan="1" rowspan="2">-</td>
<td colspan="1" rowspan="2">-</td>
</tr>
<tr>
<td class="trd1c">W</td>
<td colspan="1"></td>
</tr>
<tr class="trd1r">
<td class="trd1c">Reset</td><td>0</td><td>0</td><td>0</td><td>0</td><td>0</td><td>0</td><td>0</td><td>0</td><td>0</td><td>0</td>
<td>0</td><td>0</td><td>0</td><td>0</td><td>0</td><td>0</td>
</tr>
</table>
<table class="regtbl">
<tr class="trd1r">
<td class="trd1c">Bit</td><td>15</td><td>14</td><td>13</td><td>12</td><td>11</td><td>10</td><td>9</td><td>8</td><td>7</td>
<td>6</td><td>5</td><td>4</td><td>3</td><td>2</td><td>1</td><td>0</td>
</tr>
<tr>
<td class="trd1c">R</td><td colspan="1" rowspan="2">-</td><td colspan="1" rowspan="2">-</td><td colspan="1" rowspan="2">-</td>
<td colspan="1" rowspan="2">-</td><td colspan="1" rowspan="2">-</td><td colspan="1" rowspan="2">-</td>
<td colspan="1" rowspan="2">-</td><td colspan="1" rowspan="2">-</td><td colspan="1" rowspan="2">-</td>
<td colspan="1" rowspan="2">-</td><td colspan="1" rowspan="2">-</td><td colspan="1" rowspan="2">-</td>
<td colspan="1" rowspan="2">-</td><td colspan="1" rowspan="2">-</td><td colspan="1" rowspan="2">-</td>
<td colspan="1" rowspan="2">-</td>
</tr>
<tr>
<td class="trd1c">W</td>
</tr>
<tr class="trd1r">
<td class="trd1c">Reset</td><td>0</td><td>0</td><td>0</td><td>0</td><td>0</td><td>0</td><td>0</td><td>0</td><td>0</td><td>0</td>
<td>0</td><td>0</td><td>0</td><td>0</td><td>0</td><td>0</td>
</tr>
</table>
        
</div>
<table class="regtbl2"><tr><td class="trowtit" colspan="2">Address</td><td colspan="2">0x4002F100</td></tr>
<tr class="trowtit"><td  class="trowtit" colspan="2">Initial value</td><td colspan="2">0x41000000</td></tr>
<tr class="trowtit"><td  class="trowtit" colspan="2">After-reset value</td><td colspan="2">0x00000000</td></tr>
<tr><td class="ttitle2">Bit</td><td class="ttitle2">Field</td><td class="ttitle2">Value</td><td class="ttitle2">Description</td></tr>
<tr><td>31</td><td>DUF</td><td>0x00</td><td>Divider Update Flag</td>
<tr><td>30</td><td>MOE</td><td>0x01</td><td>MCLK Output Enable</td>
<tr><td>24 - 25</td><td>MICS</td><td>0x00</td><td>MCLK Input Clock Select</td>
</tr></table>
<div class="reghdr1">I2S0_MDR</div>
<div class="regdiag">
<table class="regtbl">
<tr class="trd1r">
<td class="trd1c">Bit</td><td>31</td><td>30</td><td>29</td><td>28</td><td>27</td><td>26</td><td>25</td><td>24</td><td>23</td>
<td>22</td><td>21</td><td>20</td><td>19</td><td>18</td><td>17</td><td>16</td>
</tr>
<tr>
<td class="trd1c">R</td><td colspan="1" rowspan="2">-</td><td colspan="1" rowspan="2">-</td><td colspan="1" rowspan="2">-</td>
<td colspan="1" rowspan="2">-</td><td colspan="1" rowspan="2">-</td><td colspan="1" rowspan="2">-</td>
<td colspan="1" rowspan="2">-</td><td colspan="1" rowspan="2">-</td><td colspan="1" rowspan="2">-</td>
<td colspan="1" rowspan="2">-</td><td colspan="1" rowspan="2">-</td><td colspan="1" rowspan="2">-</td>
<td colspan="4" rowspan="2">FRACT</td>
</tr>
<tr>
<td class="trd1c">W</td>
</tr>
<tr class="trd1r">
<td class="trd1c">Reset</td><td>0</td><td>0</td><td>0</td><td>0</td><td>0</td><td>0</td><td>0</td><td>0</td><td>0</td><td>0</td>
<td>0</td><td>0</td><td>0</td><td>0</td><td>0</td><td>0</td>
</tr>
</table>
<table class="regtbl">
<tr class="trd1r">
<td class="trd1c">Bit</td><td>15</td><td>14</td><td>13</td><td>12</td><td>11</td><td>10</td><td>9</td><td>8</td><td>7</td>
<td>6</td><td>5</td><td>4</td><td>3</td><td>2</td><td>1</td><td>0</td>
</tr>
<tr>
<td class="trd1c">R</td><td colspan="8" rowspan="2">FRACT</td><td colspan="12" rowspan="2">DIVIDE</td>
</tr>
<tr>
<td class="trd1c">W</td>
</tr>
<tr class="trd1r">
<td class="trd1c">Reset</td><td>0</td><td>0</td><td>0</td><td>0</td><td>0</td><td>0</td><td>0</td><td>0</td><td>0</td><td>0</td>
<td>0</td><td>0</td><td>0</td><td>0</td><td>0</td><td>0</td>
</tr>
</table>
        
</div>
<table class="regtbl2"><tr><td class="trowtit" colspan="2">Address</td><td colspan="2">0x4002F104</td></tr>
<tr class="trowtit"><td  class="trowtit" colspan="2">Initial value</td><td colspan="2">0x00003004</td></tr>
<tr class="trowtit"><td  class="trowtit" colspan="2">After-reset value</td><td colspan="2">0x00000000</td></tr>
<tr><td class="ttitle2">Bit</td><td class="ttitle2">Field</td><td class="ttitle2">Value</td><td class="ttitle2">Description</td></tr>
<tr><td>12 - 19</td><td>FRACT</td><td>0x00</td><td>MCLK Fraction</td>
<tr><td>0 - 11</td><td>DIVIDE</td><td>0x00</td><td>MCLK Divide</td>
</tr></table>
<div class="reghdr1">I2S0_TCSR</div>
<div class="regdiag">
<table class="regtbl">
<tr class="trd1r">
<td class="trd1c">Bit</td><td>31</td><td>30</td><td>29</td><td>28</td><td>27</td><td>26</td><td>25</td><td>24</td><td>23</td>
<td>22</td><td>21</td><td>20</td><td>19</td><td>18</td><td>17</td><td>16</td>
</tr>
<tr>
<td class="trd1c">R</td><td colspan="1" rowspan="2">TE</td><td colspan="1" rowspan="2">STOPE</td>
<td colspan="1" rowspan="2">DBGE</td><td colspan="1" rowspan="2">BCE</td><td colspan="1" rowspan="2">-</td>
<td colspan="1" rowspan="2">-</td><td colspan="1"></td><td colspan="1" rowspan="2">SR</td><td colspan="1" rowspan="2">-</td>
<td colspan="1" rowspan="2">-</td><td colspan="1" rowspan="2">-</td><td colspan="1" rowspan="2">WSF</td>
<td colspan="1" rowspan="2">SEF</td><td colspan="1" rowspan="2">FEF</td><td colspan="1" rowspan="1">FWF</td>
<td colspan="1" rowspan="1">FRF</td>
</tr>
<tr>
<td class="trd1c">W</td>
<td colspan="1">FR</td><td colspan="1"></td><td colspan="1"></td>
</tr>
<tr class="trd1r">
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

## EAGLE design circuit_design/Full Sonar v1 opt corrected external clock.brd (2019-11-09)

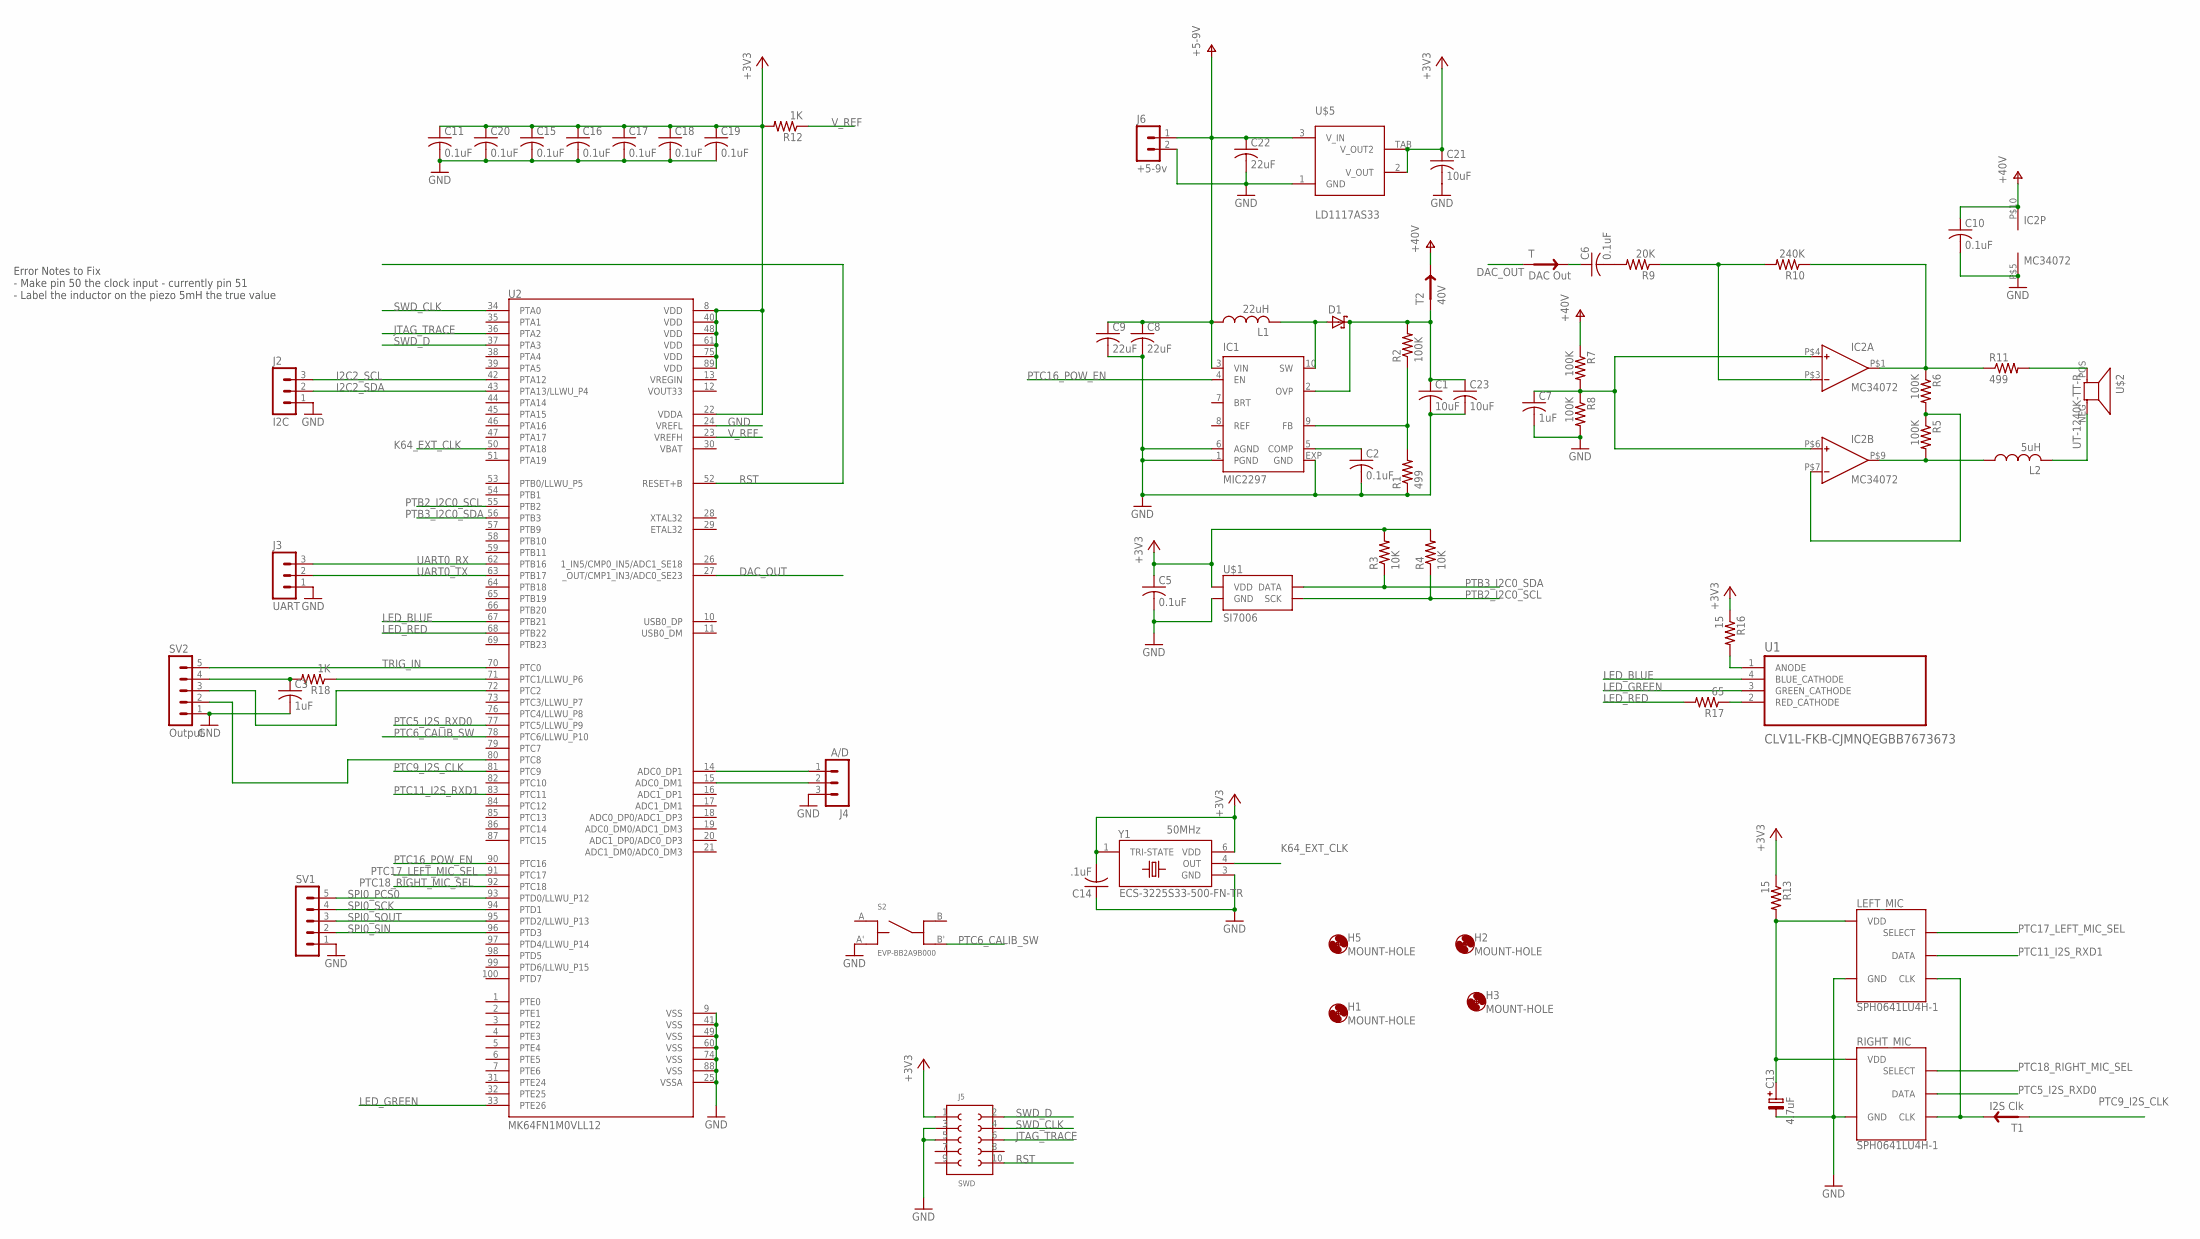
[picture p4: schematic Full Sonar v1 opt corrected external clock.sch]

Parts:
C1, C23: 10uF; C1206
C2, C5, C6, C10, C11, C16, C17, C18, C19: 0.1uF; C0603
C3, C7: 1uF; C0603
C8, C9, C22: 22uF; C0805
C13: 4.7uF; TE-A-3216
C14: .1uF; C0603
C15, C20: 0.1uF; C0603K
C21: 10uF; C0603
D1: DIODE_SCHOTTKYMICROSMP; DIODE_SCHOTTKY_MICROSMP
H1, H2, H3, H5: MOUNT-HOLE; SCREWHOLE2-56
IC1: MIC2297; MLF10
IC2: MC34072; WQFN10
J2: I2C; MA03-1
J3: UART; MA03-1
J4: A/D; MA03-1
J5: SWD; 62201021121
J6: +5-9v; MA02-1
L1: 22uH; INDUCTOR_BOURNS_SRN3012TA
L2: 5uH; INDUCTOR_BOURNS_SDR0503
LEFT_MIC: SPH0641LU4H-1
R1, R11: 499; R0603
R2, R5, R6, R7, R8: 100K; R0603
R3, R4: 10K; R0603
R9: 20K; R0603
R10: 240K; R0603
R12, R18: 1K; R0603
R13, R16: 15; R0603
R17: 65; R0603
RIGHT_MIC: SPH0641LU4H-1
S2: EVP-BB2A9B000; SW_EVP-BB2A9B000
SV1: MA05-1
SV2: Output; MA05-1
T: DAC Out; TESTPAD
T1: I2S Clk; TESTPAD
T2: 40V; TESTPAD
U1: CLV1L-FKB-CJMNQEGBB7673673; SOJ150P350X372-4N
U2: MK64FN1M0VLL12; QFP50P1600X1600X170-100N
U$1: SI7006
U$2: UT-1240K-TT-R
U$5: LD1117AS33; SOT223
Y1: ECS-3225S33-500-FN-TR; XTAL_ECS-3225S18-050-EN-TR

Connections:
+3V3: C5.1, C11.1, C14.2, C15.1, C16.1, C17.1, C18.1, C19.1, C20.1, C21.1, J5.1, R3.2, R4.2, R12.2, R13.1, R16.1, U2.8 (VDD), U2.22 (VDDA), U2.40 (VDD), U2.48 (VDD), U2.61 (VDD), U2.75 (VDD), U2.89 (VDD), U$1.VDD, U$5.2 (V_OUT), U$5.TAB (V_OUT2), Y1.1 (TRI-STATE), Y1.6 (VDD)
+5-9V: C8.1, C9.1, C22.1, IC1.3 (VIN), J6.1, L1.P$1 (1), U$5.3 (V_IN)
+40V: C1.1, C23.1, D1.C, IC1.2 (OVP), R2.2, T2.IN
DAC_OUT: T.IN, U2.27 (_OUT/CMP1_IN3/ADC0_SE23)
GND: C1.2, C2.2, C3.2, C5.2, C7.2, C8.2, C9.2, C10.2, C11.2, C13.-, C14.1, C15.2, C16.2, C17.2, C18.2, C19.2, C20.2, C21.2, C22.2, C23.2, IC1.1 (PGND), IC1.6 (AGND), IC1.EXP (GND), IC2.P$5 (V-), J2.1, J3.1, J4.3, J5.3 (2), J5.5 (3), J6.2, LEFT_MIC.3 (GND), R1.1, R8.2, RIGHT_MIC.3 (GND), S2.A', SV1.1, SV2.1, U2.9 (VSS), U2.24 (VREFL), U2.25 (VSSA), U2.41 (VSS), U2.49 (VSS), U2.60 (VSS), U2.74 (VSS), U2.88 (VSS), U$1.GND, U$5.1 (GND), Y1.3 (GND)
I2C2_SCL: J2.3, U2.42 (PTA12)
I2C2_SDA: J2.2, U2.43 (PTA13/LLWU_P4)
JTAG_TRACE: J5.6 (8), U2.36 (PTA2)
K64_EXT_CLK: U2.50 (PTA18), Y1.4 (OUT)
LED_BLUE: U1.4 (BLUE_CATHODE), U2.67 (PTB21)
LED_GREEN: U1.3 (GREEN_CATHODE), U2.33 (PTE26)
LED_RED: R17.2, U2.68 (PTB22)
unnamed: J4.1, U2.14 (ADC0_DP1)
unnamed: D1.A, IC1.10 (SW), L1.P$2 (2)
unnamed: J4.2, U2.15 (ADC0_DM1)
unnamed: R16.2, U1.1 (ANODE)
unnamed: C2.1, IC1.5 (COMP)
unnamed: IC2.P$9 (OUT), L2.1, R5.2
unnamed: IC2.P$7 (IN-), R5.1, R6.2
unnamed: IC2.P$1 (OUT), R6.1, R10.1, R11.1
unnamed: IC1.9 (FB), R1.2, R2.1
unnamed: R11.2, U$2.POS
unnamed: C7.1, IC2.P$4 (IN+), IC2.P$6 (IN+), R7.2, R8.1
unnamed: IC2.P$3 (IN-), R9.1, R10.2
unnamed: C6.2, R9.2
unnamed: L2.2, U$2.NEG
unnamed: C6.1, T.OUT
unnamed: LEFT_MIC.4 (CLK), RIGHT_MIC.4 (CLK), T1.OUT
unnamed: C13.+, LEFT_MIC.5 (VDD), R13.2, RIGHT_MIC.5 (VDD)
unnamed: R17.1, U1.2 (RED_CATHODE)
unnamed: R18.1, U2.71 (PTC1/LLWU_P6)
unnamed: C3.1, R18.2, SV2.4
unnamed: SV2.3, U2.72 (PTC2)
unnamed: SV2.2, U2.80 (PTC8)
PTB2_I2C0_SCL: R4.1, U2.55 (PTB2), U$1.SCK
PTB3_I2C0_SDA: R3.1, U2.56 (PTB3), U$1.DATA
PTC5_I2S_RXD0: RIGHT_MIC.1 (DATA), U2.77 (PTC5/LLWU_P9)
PTC6_CALIB_SW: S2.B', U2.78 (PTC6/LLWU_P10)
PTC9_I2S_CLK: T1.IN, U2.81 (PTC9)
PTC11_I2S_RXD1: LEFT_MIC.1 (DATA), U2.83 (PTC11)
PTC16_POW_EN: IC1.4 (EN), U2.90 (PTC16)
PTC17_LEFT_MIC_SEL: LEFT_MIC.2 (SELECT), U2.91 (PTC17)
PTC18_RIGHT_MIC_SEL: RIGHT_MIC.2 (SELECT), U2.92 (PTC18)
RST: J5.10 (6), U2.52 (RESET+B)
SPI0_PCS0: SV1.5, U2.93 (PTD0/LLWU_P12)
SPI0_SCK: SV1.4, U2.94 (PTD1)
SPI0_SIN: SV1.2, U2.96 (PTD3)
SPI0_SOUT: SV1.3, U2.95 (PTD2/LLWU_P13)
SWD_CLK: J5.4 (9), U2.34 (PTA0)
SWD_D: J5.2 (10), U2.37 (PTA3)
TRIG_IN: SV2.5, U2.70 (PTC0)
UART0_RX: J3.3, U2.62 (PTB16)
UART0_TX: J3.2, U2.63 (PTB17)
V+: C10.1, IC2.P$10 (V+), R7.1, T2.OUT
VBAT: U2.30 (VBAT)
VOUT33: U2.12 (VOUT33)
VREGIN: U2.13 (VREGIN)
V_REF: R12.1, U2.23 (VREFH)

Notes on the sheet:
50MHz
Error Notes to Fix - Make pin 50 the clock input - currently pin 51 - Label the inductor on the piezo 5mH the true value

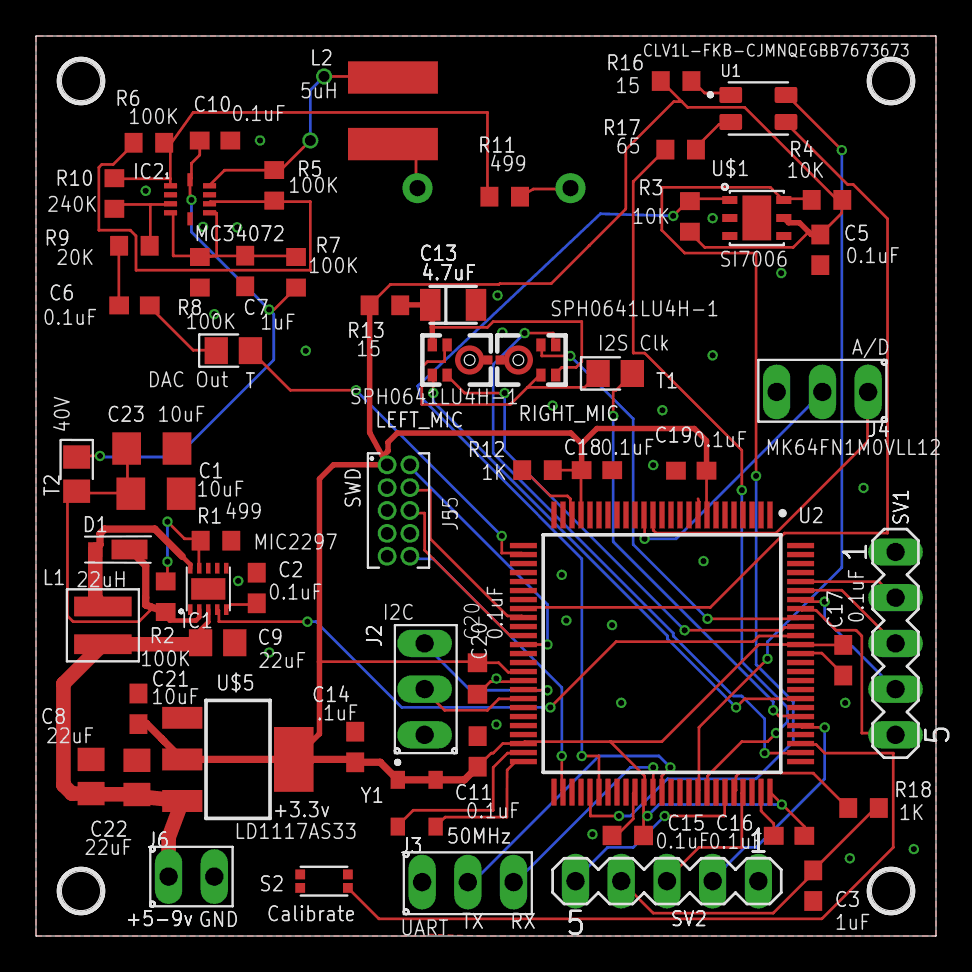
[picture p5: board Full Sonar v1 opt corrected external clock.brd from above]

Board: 2 copper layers, 50.0 x 50.0 mm, 65 parts (1 on the bottom side), 55 nets.

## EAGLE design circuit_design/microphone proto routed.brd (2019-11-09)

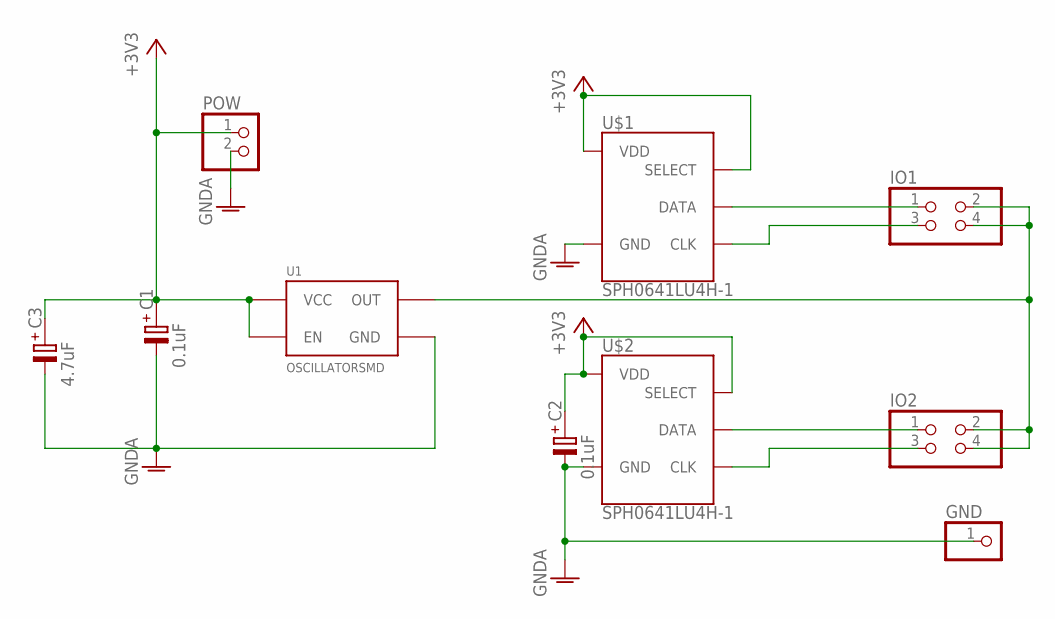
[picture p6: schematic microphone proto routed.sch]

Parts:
C1, C2: 0.1uF; 0805
C3: 4.7uF; TE-A-3216
GND: PINHD-1X1; 1X01
IO1, IO2: PINHD-2X2; 2X02
POW: PINHD-1X2; 1X02
U1: OSCILLATORSMD; CRYSTAL-SMD-7X5
U$1, U$2: SPH0641LU4H-1

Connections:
+3V3: C1.+, C2.+, C3.+, POW.1, U1.P$1 (EN), U1.P$4 (VCC), U$1.2 (SELECT), U$1.5 (VDD), U$2.2 (SELECT), U$2.5 (VDD)
GNDA: C1.-, C2.-, C3.-, GND.1, POW.2, U1.P$2 (GND), U$1.3 (GND), U$2.3 (GND)
unnamed: IO1.1, U$1.1 (DATA)
unnamed: IO1.3, U$1.4 (CLK)
unnamed: IO1.2, IO1.4, IO2.2, IO2.4, U1.P$3 (OUT)
unnamed: IO2.1, U$2.1 (DATA)
unnamed: IO2.3, U$2.4 (CLK)

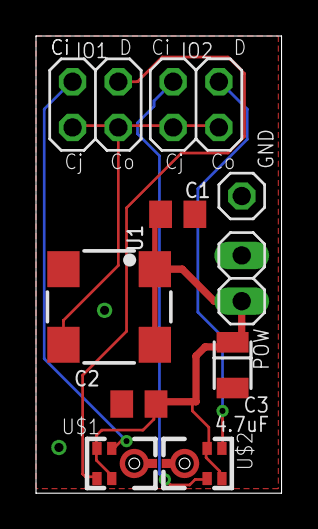
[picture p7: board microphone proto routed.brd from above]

Board: 2 copper layers, 13.6 x 25.4 mm, 10 parts (0 on the bottom side), 7 nets.

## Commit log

2017-04-27 Added a third mems input SPI0 (start does not sync with I2S) Solved issue with missing I2S bits when reading frame sizes cant be 1
2017-05-11 Tried setting up DMA, but seems to be flaky and slower. Only works when the compiler is not optimizing.
2017-05-12 Removed the DMA code since it did not work. Last version has best DMA code that I could write. It was slow and did not work well at all. Not sure it would really save much time.
2017-05-12 Changed the I2S interrupt to load 5 32 bit words at a time for each channel. THis should improve performance slightly.
2017-06-07 updated output approach to Octave to handle arbitrary sized arrays.
    shortened the size of the data sample to 1000 for quicker experiments
2017-06-22 Improved approach for serial output of arrays Made the sample length a variable that can be changed Instead of blanking for self-echos, code subtracts off the correlation when the switch SW2 on the f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
2017-07-04 Removed calc of crosscorrelation on the mems1 microphone since its not needed. This reduces calc time by about half.
    Added a calibration sequence so that when pressing SW2, it finds the
    threshold for noise (runs crosscorrelation with chirp when there is no
    output chirp) and also creates a copy of the cross correlation profile
    that is subtracted out when finding targets. This removes the
    self-echo.
    Other minor improvements
2017-07-15 Added ability to change clocks for PIT and I2S and calculate the right counts based on a chirp frequency define.
    Added ability to output the raw sound data
    Created both a baseline subtraction and blanking windows
    Changed clocks for I2S to use osc0, the 50MhZ oscilator on the board,
    which is more accurate.
2018-05-28 Added automatic calibration after 10 pulses. Added LED support Added basic support for the custom board
